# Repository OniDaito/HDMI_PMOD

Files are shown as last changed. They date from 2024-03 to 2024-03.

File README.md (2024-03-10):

# HDMI Compatible PMOD board for Arty A7

This is KiCAD project, complete with Gerbers, for a HDMI Compatible PMOD controller. Plug this into one of your PMOD sockets on your Arty A7 and you have a working HDMI compatible socket.

## Bill of Materials (BOM)

* Texas Instruments TPS61222DCKT Boost Convertor [RS Components Link](https://uk.rs-online.com/web/p/boost-converters/1627959)
* Inductor L1 4.7uH  - [Mouser Link](https://www.mouser.co.uk/ProductDetail/TDK/TMS322512ALM-4R7MTAA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)
* Capacitors C1, C2 10uF 0805/2012 - [Mouser Link](https://www.mouser.co.uk/ProductDetail/KYOCERA-AVX/0805YC106KAT2A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)
* HDMI Socket -  [Mouser Link](https://www.mouser.co.uk/ProductDetail/Molex/208658-1001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)
* Right Angle Molex 2 x 6 socket -  [Mouser Link](https://www.mouser.co.uk/ProductDetail/Molex/90122-0126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)
* This board.

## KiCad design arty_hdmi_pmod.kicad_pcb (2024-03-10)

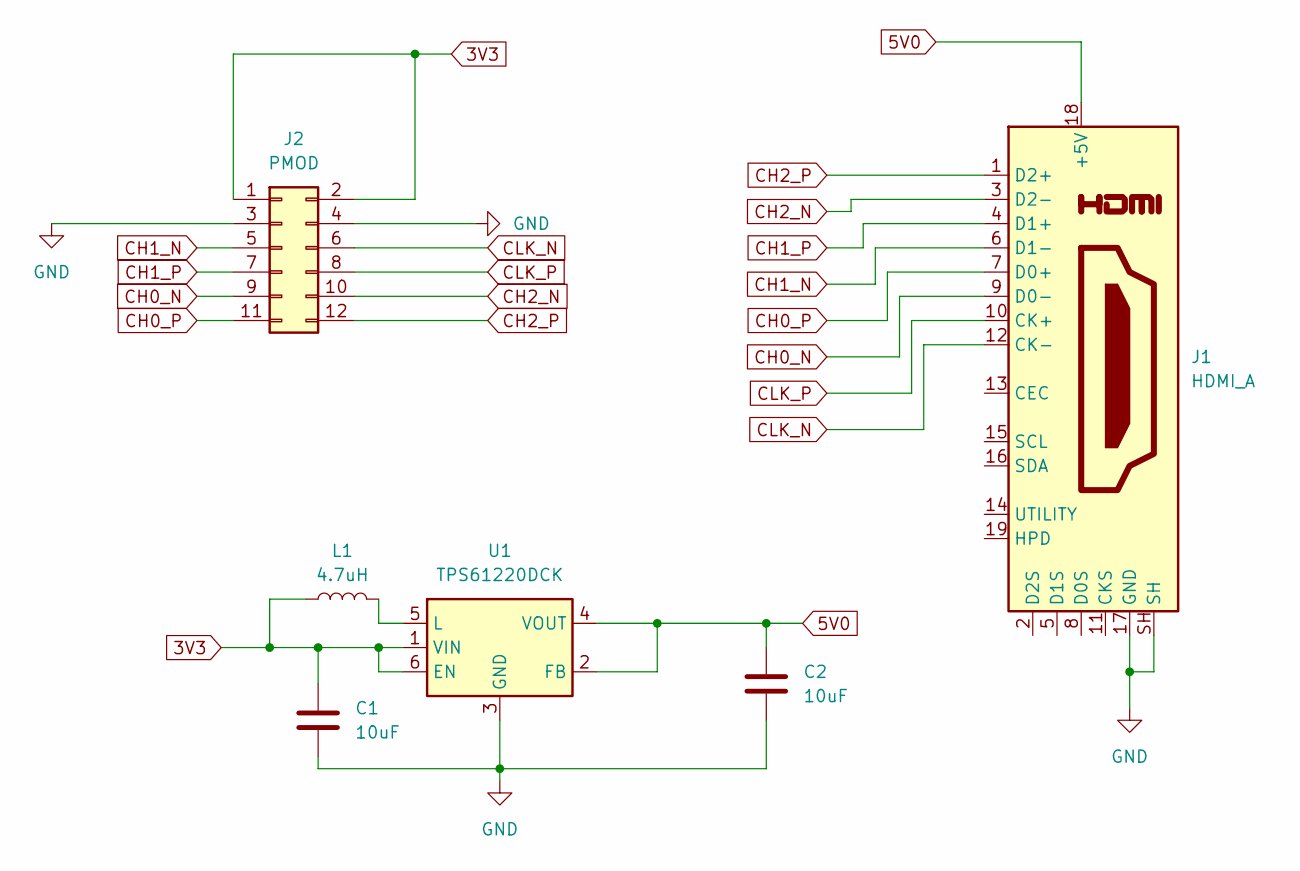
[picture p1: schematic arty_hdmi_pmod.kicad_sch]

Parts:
C1, C2: 10uF; C_0805_2012Metric_Pad1.18x1.45mm_HandSolder
J1: HDMI_A; HDMI_A_Molex_208658-1001_Horizontal
J2: PMOD; PinHeader_2x06_P2.54mm_Vertical
L1: 4.7uH; L_Coilcraft_XxL4040
U1: TPS61220DCK; Texas_R-PDSO-G6

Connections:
3V3: C1.1, J2.1, J2.2, L1.1, U1.1 (VIN), U1.6 (EN)
5V0: C2.1, J1.18 (+5V), U1.2 (FB), U1.4 (VOUT)
CH0_N: J1.9 (D0-), J2.9
CH0_P: J1.7 (D0+), J2.11
CH1_N: J1.6 (D1-), J2.5
CH1_P: J1.4 (D1+), J2.7
CH2_N: J1.3 (D2-), J2.10
CH2_P: J1.1 (D2+), J2.12
CLK_N: J1.12 (CK-), J2.6
CLK_P: J1.10 (CK+), J2.8
GND: C1.2, C2.2, J1.17 (GND), J1.SH, J2.3, J2.4, U1.3 (GND); also elsewhere on the board
unnamed: L1.2, U1.5 (L)

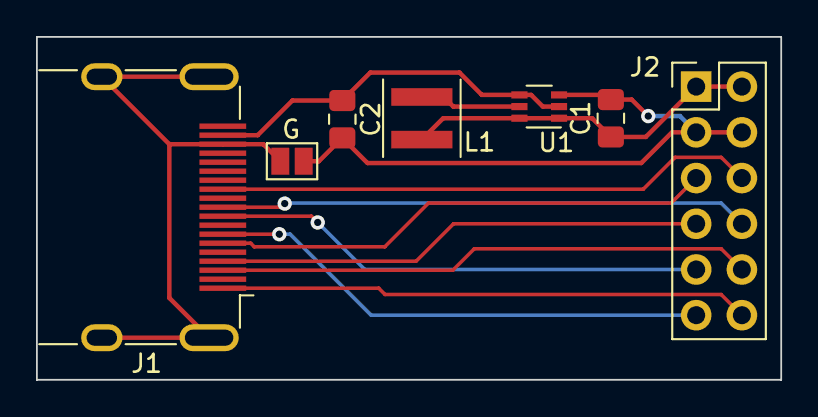
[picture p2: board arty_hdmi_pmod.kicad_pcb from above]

Board: 2 copper layers, 41.4 x 19.1 mm, 7 parts (0 on the bottom side), 12 nets.

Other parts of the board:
G: SolderJumper-2_P1.3mm_Open_Pad1.0x1.5mm

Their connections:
GND: G.1, G.2; also elsewhere on the board
